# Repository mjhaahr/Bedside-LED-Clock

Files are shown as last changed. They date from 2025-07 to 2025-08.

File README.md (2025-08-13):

# RGB LED 7-Segment Bedside Clock with Ambient Light and Proximity Sensor

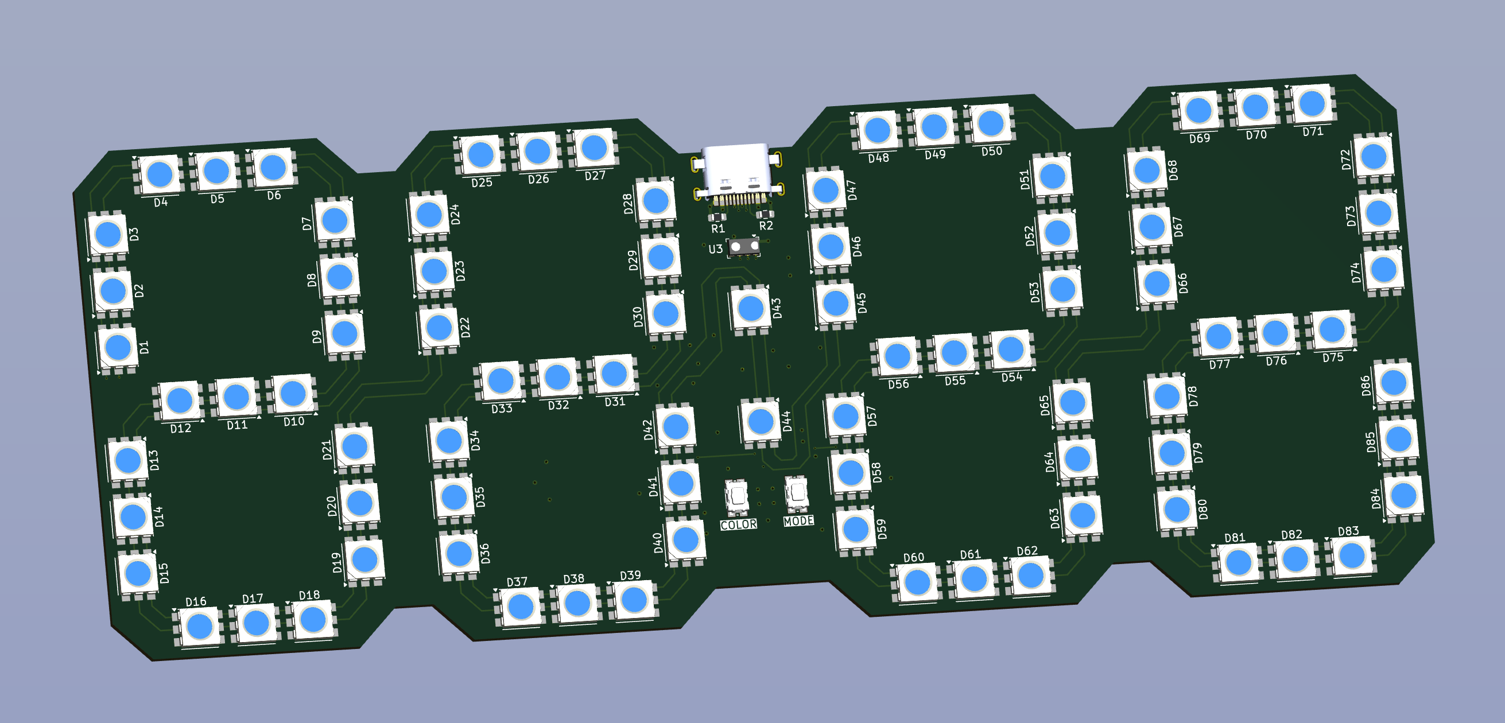
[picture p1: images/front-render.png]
Full Board Design Render - Front

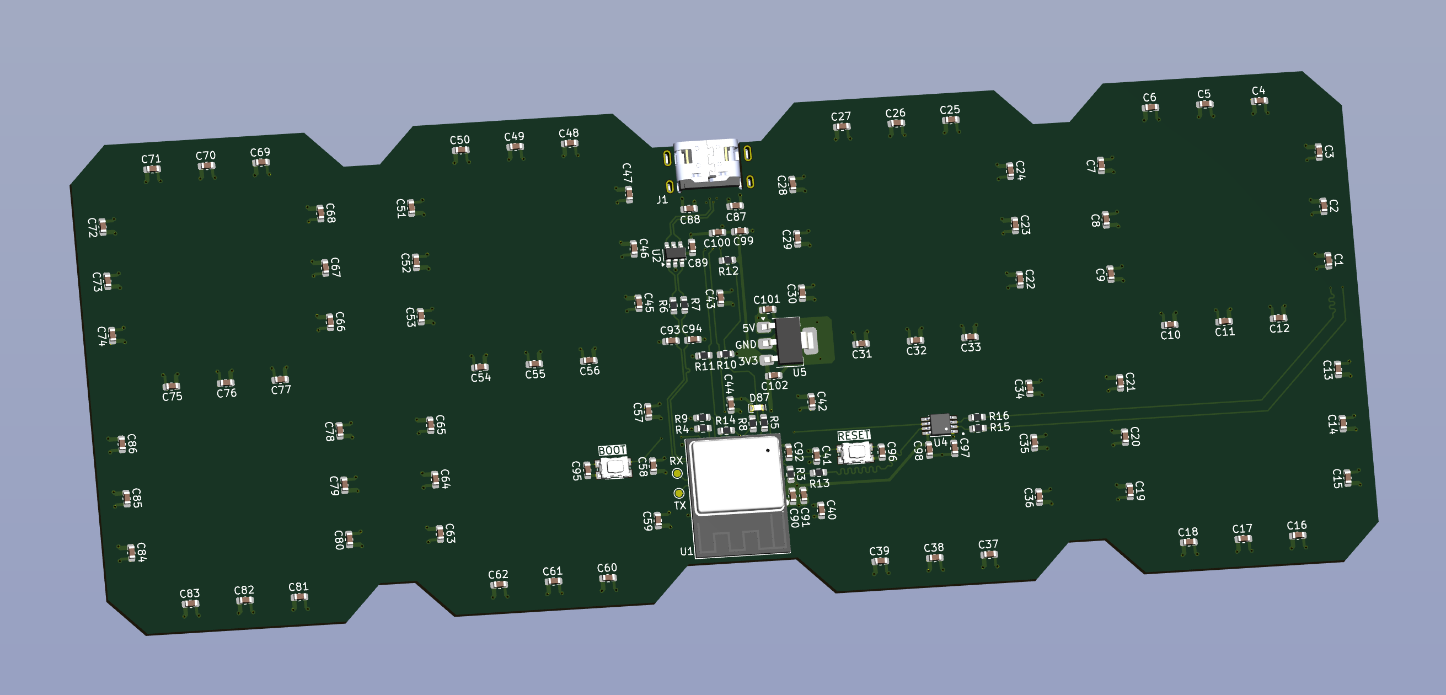
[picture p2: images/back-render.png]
Full Board Design Render - Back


## Features
- USB C Port for Power, Comms, and Programming
    - Connects to the ESP32-C3's onboard USB-CDC/JTAG device
- ESP32-C3 Module for control
    - Allows pattern changing over WiFi/Bluetooth, as well as the buttons on the device
- Integrated Ambient Light and Proximity Sensor
    - Allows the clock to be used at night and stay idle unless desired
- 86 Addressable RGB LEDs
    - APA102-style (DotStar) 2-Wire Control with Global Dimmer and Clock
    - HD107S-5050
    
## Table Of Contents
- [Features](#features)
- [Bill Of Materials](#bill-of-materials)
- [Part Selection](#part-selection)
- [Case Design](#case-design)
- [Code](#code)
- [Extra Notes](#extra-notes)

Main Schematic
Digit Schematic (Repeated 4x)

## Bill of Materials
<!--  
- NAME - FUNC
    - Component: REF
    - Quantity: 
    - [Datasheet]()
    - [DigiKey]()
-->
- Espressif ESP32-C3-MINI-1 - Microcontroller Module w/ WiFi and Bluetooth
    - Component: U1
    - Quantity: 1
    - [Datasheet](https://www.espressif.com/sites/default/files/documentation/esp32-c3-mini-1_datasheet_en.pdf)
    - [DigiKey](https://www.digikey.com/en/products/detail/espressif-systems/ESP32-C3-MINI-1-N4-A/15817506)
- STMicroelectronics USBLC6-2SC6 - USB Data and Power TVS Diode
    - Component: U2
    - Quantity: 1
    - [Datasheet](https://www.st.com/content/ccc/resource/technical/document/datasheet/06/1d/48/9c/6c/20/4a/b2/CD00050750.pdf/files/CD00050750.pdf/jcr:content/translations/en.CD000507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)
    - [DigiKey](https://www.digikey.com/en/products/detail/stmicroelectronics/USBLC6-2SC6/1040559)
- Vishay VCNL4040M3OE - Combination Ambient Light and Proximity Sensor
    - Component: U3
    - Quantity: 1
    - [Datasheet](https://www.vishay.com/docs/84274/vcnl4040.pdf)
    - [DigiKey](https://www.digikey.com/en/products/detail/vishay-semiconductor-opto-division/VCNL4040M3OE/5171283)
- TI SN74LVC2T45DCTR - Two Channel Fast Level Shifter (from 3V3 MCU to 5V LEDs)
    - Component: U4
    - Quantity: 1
    - [Datasheet](https://www.ti.com/lit/ds/symlink/sn74lvc2t45.pdf)
    - [DigiKey](https://www.digikey.com/en/products/detail/texas-instruments/SN74LVC2T45DCTR/639457)
- Microchip MCP1825ST-3302E/DB - 3V3 Low Noise LDO (500mA)
    - Component: U5
    - Quantity: 1
    - [Datasheet](https://ww1.microchip.com/downloads/en/DeviceDoc/22056b.pdf)
    - [DigiKey](https://www.digikey.com/en/products/detail/microchip-technology/MCP1825ST-3302E-DB/1635518)
- HD107S - APA102 Style Addressable RGB LED with Global Dimmer and Clock 
    - Component: D1 - D86
    - Quantity: 86
    - [Datasheet](https://cdn.hackaday.io/files/1677667177700544/HD107S%20%20Pixel%20RGB%205050%20LED%20chip%20%20Specificaion%20V1.0.1.pdf)
    - [LED Lighting Hut](https://www.ledlightinghut.com/hd107s-5050-rgb-led.html)
- Würth Elektronik 150060VS55040 - Green Indicator LED (LED_BUILTIN)
    - Component: D87
    - Quantity: 1
    - [Datasheet](https://www.we-online.com/components/products/datasheet/150060VS55040.pdf)
    - [DigiKey](https://www.digikey.com/en/products/detail/w%C3%BCrth-elektronik/150060VS55040/8557182)
- GCT USB4520-03-0-A - Midmount USB 2.0 Type C Port
    - Component: J1
    - Quantity: 1
    - [Datasheet](https://gct.co/files/specs/usb4520-spec.pdf)
    - [DigiKey](https://www.digikey.com/en/products/detail/gct/USB4520-03-0-A/15283199)
- E-Switch TL6330AF200Q - Tactile Normally Open Push Button 
    - Component: SW1 - SW4
    - Quantity: 4
    - [Datasheet](https://configured-product-images.s3.amazonaws.com/Datasheets/TL6330.pdf)
    - [DigiKey](https://www.digikey.com/en/products/detail/e-switch/TL6330AF200Q/8032037)
- 100nF - Yageo 0603 Ceramic Capacitor
    - Component: C1 - C86, C89, C91, C96, C98, C99
    - Quantity: 13
    - [DigiKey](https://www.digikey.com/en/products/detail/yageo/CC0603KRX7R7BB104/302822)
- 1µF - Yageo 0603 Ceramic Capacitor
    - Component: C87, C92, C102
    - Quantity: 3
    - [DigiKey](https://www.digikey.com/en/products/detail/yageo/CC0603KRX5R8BB105/2833610)
- 10µF - Yageo 0603 Ceramic Capacitor
    - Component: C88, C90, C97
    - Quantity: 3
    - [DigiKey](https://www.digikey.com/en/products/detail/yageo/CC0603MRX5R6BB106/5195224)
- 22pF - Yageo 0603 Ceramic Capacitor
    - Component: C93, C94
    - Quantity: 2
    - [DigiKey](https://www.digikey.com/en/products/detail/yageo/CC0603JRNPO8BN220/5883592)
- 2.2µF - Yageo 0603 Ceramic Capacitor
    - Component: C100
    - Quantity: 1
    - [DigiKey](https://www.digikey.com/en/products/detail/yageo/CC0603KRX5R7BB225/5195192)
- 4.7µF - Yageo 0603 Ceramic Capacitor
    - Component: C101
    - Quantity: 1
    - [DigiKey](https://www.digikey.com/en/products/detail/yageo/CC0603KRX5R7BB475/5195193)
- 5.1kΩ - Yageo 0603 SMD Resistor
    - Component: R1, R2
    - Quantity: 2
    - [DigiKey](https://www.digikey.com/en/products/detail/yageo/RC0603FR-075K1L/727268)
- 10kΩ - Yageo 0603 SMD Resistor
    - Component: R3, R4, R8, R9
    - Quantity: 4
    - [DigiKey](https://www.digikey.com/en/products/detail/yageo/RC0603FR-1010KL/12756395)
- 1.43kΩ - Yageo 0603 SMD Resistor
    - Component: R5
    - Quantity: 1
    - [DigiKey](https://www.digikey.com/en/products/detail/yageo/RC0603FR-071K43L/726862)
- 0Ω - Yageo 0603 SMD Resistor
    - Component: R6, R7
    - Quantity: 2
    - [DigiKey](https://www.digikey.com/en/products/detail/yageo/RC0603JR-070RL/726675)
- 3.3kΩ - Yageo 0603 SMD Resistor
    - Component: R10, R11
    - Quantity: 2
    - [DigiKey](https://www.digikey.com/en/products/detail/yageo/RC0603FR-073K3L/727126)
- 8.2kΩ - Yageo 0603 SMD Resistor
    - Component: R12
    - Quantity: 1
    - [DigiKey](https://www.digikey.com/en/products/detail/yageo/RC0603FR-078K2L/727390)
- 33Ω - Yageo 0603 SMD Resistor
    - Component: R13 - R16
    - Quantity: 4
    - [DigiKey](https://www.digikey.com/en/products/detail/yageo/RC0603FR-0733RL/727158)

## Case Design
<!--  TODO: Case design needs to be updated  -->
<!--  ![Case](images/case.png)  -->
- 3D Printed Chassis

## Code
<!-- Nothing Written Yet -->
- To view all the code, see it [here](code)

## Extra Notes

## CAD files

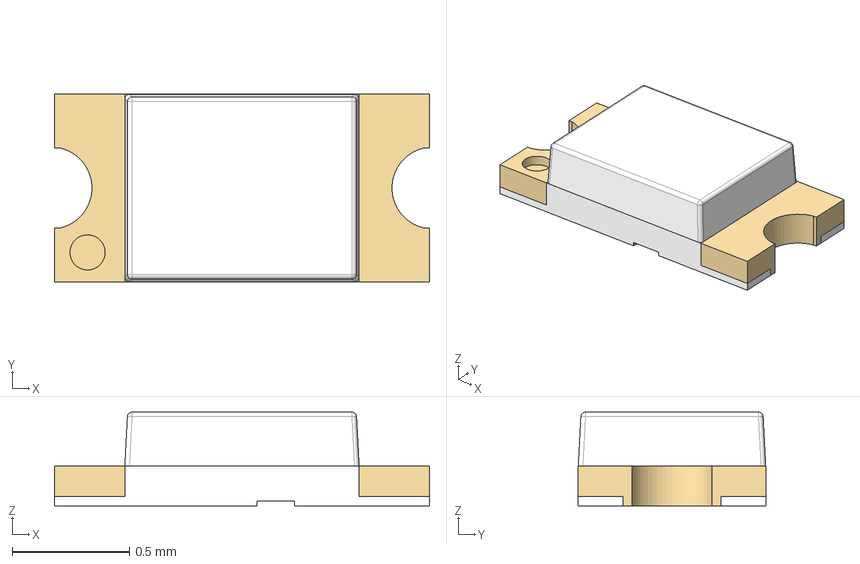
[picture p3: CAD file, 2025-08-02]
Bedside_Clock/parts/150060VS55040/WL-SMCD_0603.step
1.60 x 0.8 x 0.4 mm
housing
cover
base-oa0
base

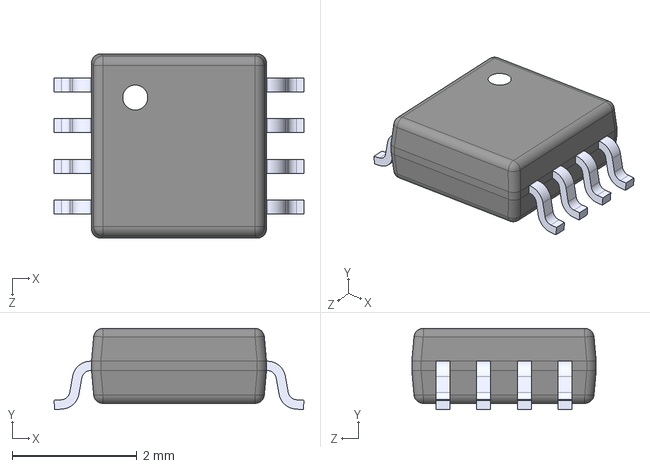
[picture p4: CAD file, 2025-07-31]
Bedside_Clock/parts/SN74LVC2T45DCTR/SN74LVC2T45DCTR.step
4.00 x 1.30 x 2.95 mm

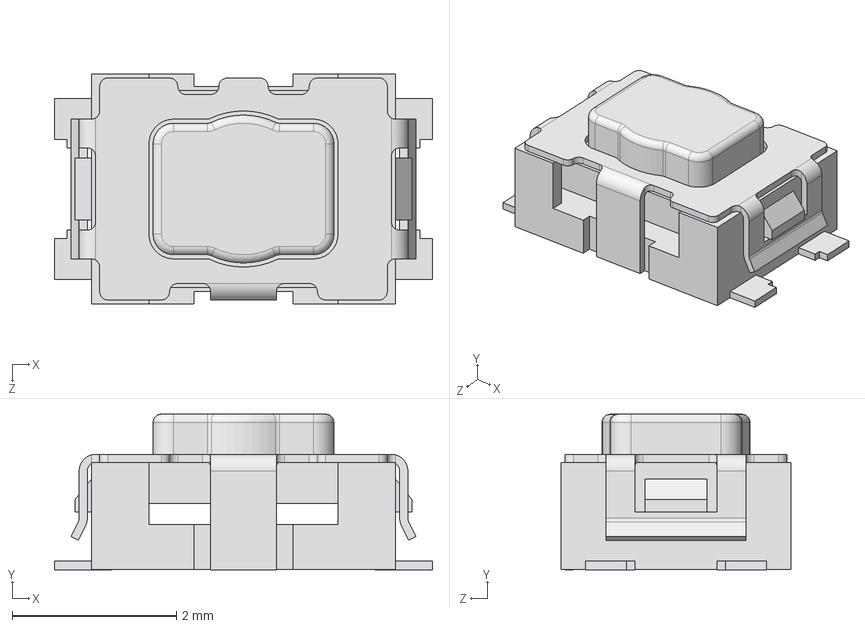
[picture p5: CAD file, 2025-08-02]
Bedside_Clock/parts/TL6330AF200Q/TL6330AF200Q.step
4.60 x 1.90 x 2.80 mm

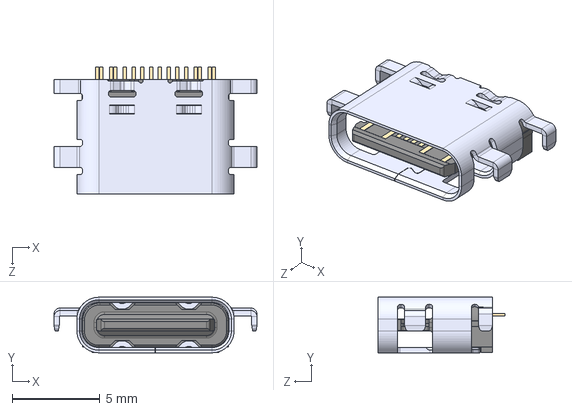
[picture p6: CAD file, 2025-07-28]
Bedside_Clock/parts/USB4520_03_0_A/USB4520-03-0-A_REVA.step
11.5 x 3.16 x 7.20 mm

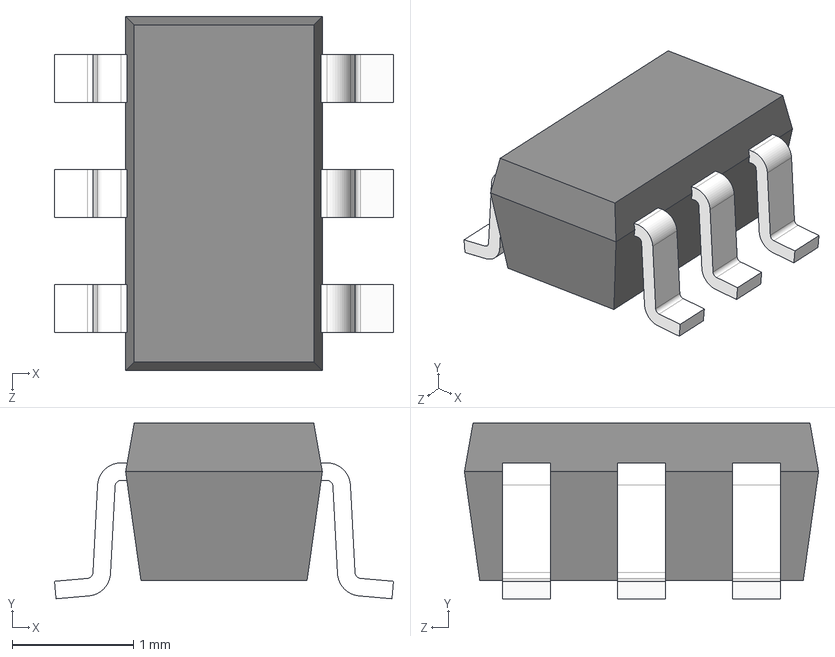
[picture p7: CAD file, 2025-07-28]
Bedside_Clock/parts/USBLC6_2SC6/USBLC6-2SC6.step
2.80 x 1.45 x 2.92 mm

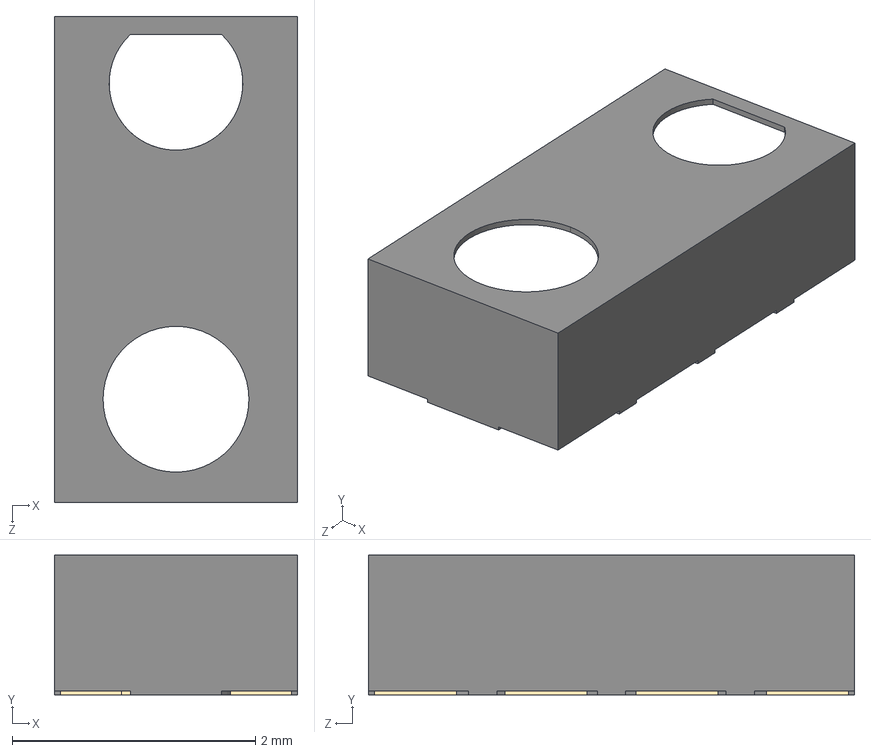
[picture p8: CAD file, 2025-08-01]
Bedside_Clock/parts/VCNL4040M3OE/VCNL4040M3OE.step
2.00 x 1.15 x 4.00 mm

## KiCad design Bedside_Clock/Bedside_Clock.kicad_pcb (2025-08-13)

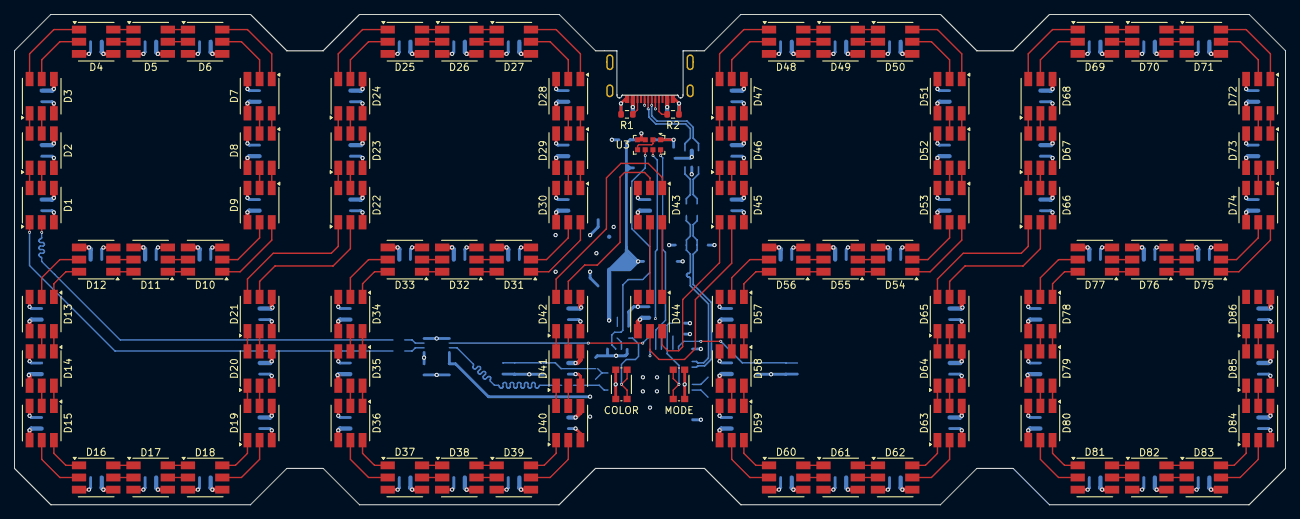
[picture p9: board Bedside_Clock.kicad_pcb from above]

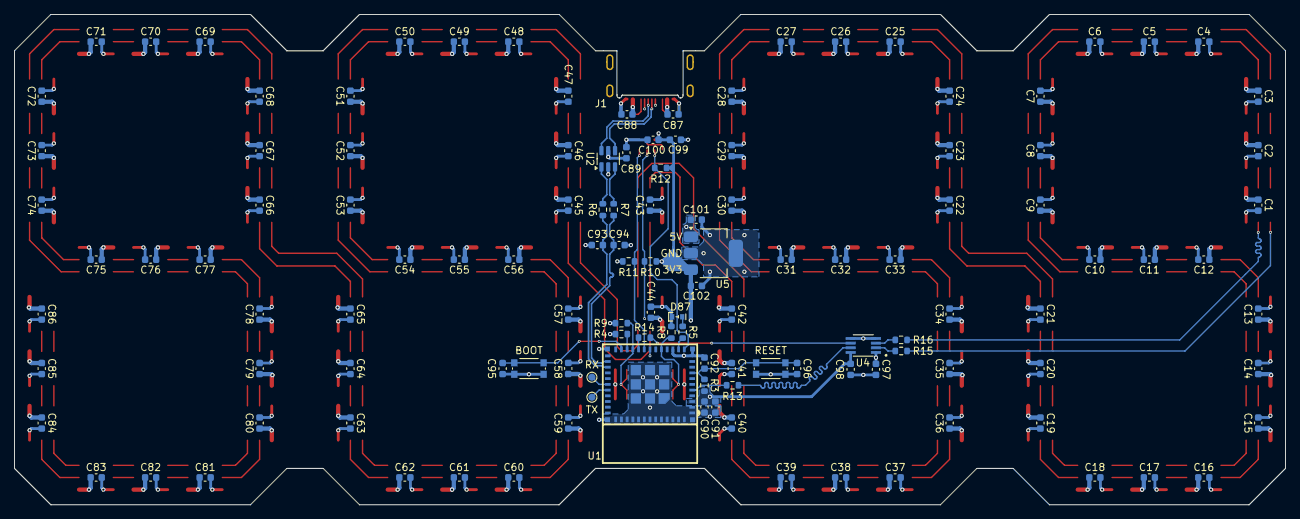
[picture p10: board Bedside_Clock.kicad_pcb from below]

Board: 4 copper layers, 177.8 x 68.6 mm, 217 parts (125 on the bottom side), 202 nets.

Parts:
C1, C2, C3, C4, C5, C6, C7, C8, C9, C10, C11, C12, C13, C14, C15, C16, C17, C18, C19, C20, C21, C22, C23, C24, C25, C26, C27, C28, C29, C30, C31, C32, C33, C34, C35, C36, C37, C38, C39, C40, C41, C42, C43, C44, C45, C46, C47, C48, C49, C50, C51, C52, C53, C54, C55, C56, C57, C58, C59, C60, C61, C62, C63, C64, C65, C66, C67, C68, C69, C70, C71, C72, C73, C74, C75, C76, C77, C78, C79, C80, C81, C82, C83, C84, C85, C86, C89, C91, C95, C96, C98, C99: 100nF; C_0603_1608Metric
C87, C92, C102: 1uF; C_0603_1608Metric
C88, C90, C97: 10uF; C_0603_1608Metric
C93, C94: 22pF; C_0603_1608Metric
C100: 2.2uF; C_0603_1608Metric
C101: 4.7uF; C_0603_1608Metric
D1, D2, D3, D4, D5, D6, D7, D8, D9, D10, D11, D12, D13, D14, D15, D16, D17, D18, D19, D20, D21, D22, D23, D24, D25, D26, D27, D28, D29, D30, D31, D32, D33, D34, D35, D36, D37, D38, D39, D40, D41, D42, D43, D44, D45, D46, D47, D48, D49, D50, D51, D52, D53, D54, D55, D56, D57, D58, D59, D60, D61, D62, D63, D64, D65, D66, D67, D68, D69, D70, D71, D72, D73, D74, D75, D76, D77, D78, D79, D80, D81, D82, D83, D84, D85, D86: HD107S; LED_RGB_5050-6
D87: WL-SMCD_0603
J1: USBC_USB2.0; GCT_USB4520-03-0-A_REVA
R1, R2: 5k1; R_0603_1608Metric
R3, R4, R8, R9: 10k; R_0603_1608Metric
R5: 1k43; R_0603_1608Metric
R6, R7: 0; R_0603_1608Metric
R10, R11: 3k3; R_0603_1608Metric
R12: 8k2; R_0603_1608Metric
R13, R14, R15, R16: 33; R_0603_1608Metric
SW1: COLOR; SW_TL6330AF200Q
SW2: MODE; SW_TL6330AF200Q
SW3: BOOT; SW_TL6330AF200Q
SW4: RESET; SW_TL6330AF200Q
TP1: TX; TestPoint_Pad_D1.0mm
TP2: RX; TestPoint_Pad_D1.0mm
U1: ESP32-C3-MINI-1; WIFIM-SMD_ESP32-C3-MINI-1
U2: USBLC6-2SC6; SOT-23-6
U3: VCNL4040M3OE; VISHAY_VCNL4040_4X2X1.1
U4: SN74LVC2T45DCTR; SOP65P400X130-8N
U5: MCP1825S; SOT-223-3_TabPin2

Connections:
+3V3: C90.1, C91.1, C98.1, C99.1, C100.1, C102.1, R3.1, R4.2, R10.2, R11.2, R12.2, SW1.1, SW1.2, SW2.1, SW2.2, U1.3 (3V3), U3.3, U3.4, U4.8 (VCCB), U5.3 (VO)
+5V: C1.1, C2.1, C3.1, C4.1, C5.1, C6.1, C7.1, C8.1, C9.1, C10.1, C11.1, C12.1, C13.1, C14.1, C15.1, C16.1, C17.1, C18.1, C19.1, C20.1, C21.1, C22.1, C23.1, C24.1, C25.1, C26.1, C27.1, C28.1, C29.1, C30.1, C31.1, C32.1, C33.1, C34.1, C35.1, C36.1, C37.1, C38.1, C39.1, C40.1, C41.1, C42.1, C43.1, C44.1, C45.1, C46.1, C47.1, C48.1, C49.1, C50.1, C51.1, C52.1, C53.1, C54.1, C55.1, C56.1, C57.1, C58.1, C59.1, C60.1, C61.1, C62.1, C63.1, C64.1, C65.1, C66.1, C67.1, C68.1, C69.1, C70.1, C71.1, C72.1, C73.1, C74.1, C75.1, C76.1, C77.1, C78.1, C79.1, C80.1, C81.1, C82.1, C83.1, C84.1, C85.1, C86.1, C87.1, C88.1, C89.1, C97.1, C101.1, D1.4 (VCC), D2.4 (VCC), D3.4 (VCC), D4.4 (VCC), D5.4 (VCC), D6.4 (VCC), D7.4 (VCC), D8.4 (VCC), D9.4 (VCC), D10.4 (VCC), D11.4 (VCC), D12.4 (VCC), D13.4 (VCC), D14.4 (VCC), D15.4 (VCC), D16.4 (VCC), D17.4 (VCC), D18.4 (VCC), D19.4 (VCC), D20.4 (VCC), D21.4 (VCC), D22.4 (VCC), D23.4 (VCC), D24.4 (VCC), D25.4 (VCC), D26.4 (VCC), D27.4 (VCC), D28.4 (VCC), D29.4 (VCC), D30.4 (VCC), D31.4 (VCC), D32.4 (VCC), D33.4 (VCC), D34.4 (VCC), D35.4 (VCC), D36.4 (VCC), D37.4 (VCC), D38.4 (VCC), D39.4 (VCC), D40.4 (VCC), D41.4 (VCC), D42.4 (VCC), D43.4 (VCC), D44.4 (VCC), D45.4 (VCC), D46.4 (VCC), D47.4 (VCC), D48.4 (VCC), D49.4 (VCC), D50.4 (VCC), D51.4 (VCC), D52.4 (VCC), D53.4 (VCC), D54.4 (VCC), D55.4 (VCC), D56.4 (VCC), D57.4 (VCC), D58.4 (VCC), D59.4 (VCC), D60.4 (VCC), D61.4 (VCC), D62.4 (VCC), D63.4 (VCC), D64.4 (VCC), D65.4 (VCC), D66.4 (VCC), D67.4 (VCC), D68.4 (VCC), D69.4 (VCC), D70.4 (VCC), D71.4 (VCC), D72.4 (VCC), D73.4 (VCC), D74.4 (VCC), D75.4 (VCC), D76.4 (VCC), D77.4 (VCC), D78.4 (VCC), D79.4 (VCC), D80.4 (VCC), D81.4 (VCC), D82.4 (VCC), D83.4 (VCC), D84.4 (VCC), D85.4 (VCC), D86.4 (VCC), J1.A4_B9 (VBUS), J1.B4_A9 (VBUS), U2.5 (VBUS), U4.1 (VCCA), U5.1 (VI)
/BOOT: C95.1, SW3.1, SW3.2, U1.23 (GPIO9)
/CC1: J1.A5 (CC1), R2.2
/CC2: J1.B5 (CC2), R1.2
/CHIP_EN: C92.1, C96.1, R3.2, SW4.1, SW4.2, U1.8 (EN/CHIP_PU)
/CO: R14.2, U4.6 (B2)
/CO': R14.1, U1.20 (GPIO6)
/CO'': R16.1, U4.3 (A2)
/COLOR: R8.1, SW1.3, SW1.4, U1.16 (GPIO10)
/DO: R13.2, U4.7 (B1)
/DO': R13.1, U1.5 (GPIO2/ADC1_CH2)
/DO'': R15.1, U4.2 (A1)
/Digit0/CI: D1.2 (CI), R16.2
/Digit0/CO: D21.5 (CO), D22.2 (CI)
/Digit0/DI: D1.1 (DI), R15.2
/Digit0/DO: D21.6 (DO), D22.1 (DI)
/Digit1/CO: D42.5 (CO), D43.2 (CI)
/Digit1/DO: D42.6 (DO), D43.1 (DI)
/Digit2/CI: D44.5 (CO), D45.2 (CI)
/Digit2/CO: D65.5 (CO), D66.2 (CI)
/Digit2/DI: D44.6 (DO), D45.1 (DI)
/Digit2/DO: D65.6 (DO), D66.1 (DI)
/LED_BUILTIN: R5.2, U1.13 (GPIO1/ADC1_CH1/XTAL_32K_N)
/MODE: R9.1, SW2.3, SW2.4, U1.21 (GPIO7)
/PROX_INT: R12.1, U1.12 (GPIO0/ADC1_CH0/XTAL_32K_P), U3.6
/SCL: R11.1, U1.19 (GPIO5/ADC2_CH0), U3.8
/SDA: R10.1, U1.18 (GPIO4/ADC1_CH4), U3.7
/UD''+: J1.A6 (D+), J1.B6 (D+), U2.6 (I/O1)
/UD''-: J1.A7 (D-), J1.B7 (D-), U2.4 (I/O2)
/UD'+: C93.1, R6.1, U1.27 (GPIO19/USB_D+)
/UD'-: C94.1, R7.1, U1.26 (GPIO18/USB_D-)
/UD+: R6.2, U2.1 (I/O1)
/UD-: R7.2, U2.3 (I/O2)
GND: C1.2, C2.2, C3.2, C4.2, C5.2, C6.2, C7.2, C8.2, C9.2, C10.2, C11.2, C12.2, C13.2, C14.2, C15.2, C16.2, C17.2, C18.2, C19.2, C20.2, C21.2, C22.2, C23.2, C24.2, C25.2, C26.2, C27.2, C28.2, C29.2, C30.2, C31.2, C32.2, C33.2, C34.2, C35.2, C36.2, C37.2, C38.2, C39.2, C40.2, C41.2, C42.2, C43.2, C44.2, C45.2, C46.2, C47.2, C48.2, C49.2, C50.2, C51.2, C52.2, C53.2, C54.2, C55.2, C56.2, C57.2, C58.2, C59.2, C60.2, C61.2, C62.2, C63.2, C64.2, C65.2, C66.2, C67.2, C68.2, C69.2, C70.2, C71.2, C72.2, C73.2, C74.2, C75.2, C76.2, C77.2, C78.2, C79.2, C80.2, C81.2, C82.2, C83.2, C84.2, C85.2, C86.2, C87.2, C88.2, C89.2, C90.2, C91.2, C92.2, C93.2, C94.2, C95.2, C96.2, C97.2, C98.2, C99.2, C100.2, C101.2, C102.2, D1.3 (GND), D2.3 (GND), D3.3 (GND), D4.3 (GND), D5.3 (GND), D6.3 (GND), D7.3 (GND), D8.3 (GND), D9.3 (GND), D10.3 (GND), D11.3 (GND), D12.3 (GND), D13.3 (GND), D14.3 (GND), D15.3 (GND), D16.3 (GND), D17.3 (GND), D18.3 (GND), D19.3 (GND), D20.3 (GND), D21.3 (GND), D22.3 (GND), D23.3 (GND), D24.3 (GND), D25.3 (GND), D26.3 (GND), D27.3 (GND), D28.3 (GND), D29.3 (GND), D30.3 (GND), D31.3 (GND), D32.3 (GND), D33.3 (GND), D34.3 (GND), D35.3 (GND), D36.3 (GND), D37.3 (GND), D38.3 (GND), D39.3 (GND), D40.3 (GND), D41.3 (GND), D42.3 (GND), D43.3 (GND), D44.3 (GND), D45.3 (GND), D46.3 (GND), D47.3 (GND), D48.3 (GND), D49.3 (GND), D50.3 (GND), D51.3 (GND), D52.3 (GND), D53.3 (GND), D54.3 (GND), D55.3 (GND), D56.3 (GND), D57.3 (GND), D58.3 (GND), D59.3 (GND), D60.3 (GND), D61.3 (GND), D62.3 (GND), D63.3 (GND), D64.3 (GND), D65.3 (GND), D66.3 (GND), D67.3 (GND), D68.3 (GND), D69.3 (GND), D70.3 (GND), D71.3 (GND), D72.3 (GND), D73.3 (GND), D74.3 (GND), D75.3 (GND), D76.3 (GND), D77.3 (GND), D78.3 (GND), D79.3 (GND), D80.3 (GND), D81.3 (GND), D82.3 (GND), D83.3 (GND), D84.3 (GND), D85.3 (GND), D86.3 (GND), D87.1, J1.A1_B12 (GND), J1.B1_A12 (GND), J1.S1 (SHIELD), J1.S2 (SHIELD), J1.S3 (SHIELD), J1.S4 (SHIELD), R1.1, R2.1, R8.2, R9.2, SW3.3, SW3.4, SW4.3, SW4.4, U1.1 (GND), U1.2 (GND), U1.11 (GND), U1.14 (GND), U1.36 (GND), U1.37 (GND), U1.38 (GND), U1.39 (GND), U1.40 (GND), U1.41 (GND), U1.42 (GND), U1.43 (GND), U1.44 (GND), U1.45 (GND), U1.46 (GND), U1.47 (GND), U1.48 (GND), U1.49 (GND), U1.50 (GND), U1.51 (GND), U1.52 (GND), U1.53 (GND), U2.2 (GND), U3.1, U4.4 (GND), U4.5 (DIR), U5.2 (GND)
unnamed: D1.5 (CO), D2.2 (CI)
unnamed: D1.6 (DO), D2.1 (DI)
unnamed: D2.5 (CO), D3.2 (CI)
unnamed: D2.6 (DO), D3.1 (DI)
unnamed: D3.5 (CO), D4.2 (CI)
unnamed: D3.6 (DO), D4.1 (DI)
unnamed: D4.5 (CO), D5.2 (CI)
unnamed: D4.6 (DO), D5.1 (DI)
unnamed: D5.5 (CO), D6.2 (CI)
unnamed: D5.6 (DO), D6.1 (DI)
unnamed: D6.5 (CO), D7.2 (CI)
unnamed: D6.6 (DO), D7.1 (DI)
unnamed: D7.5 (CO), D8.2 (CI)
unnamed: D7.6 (DO), D8.1 (DI)
unnamed: D8.5 (CO), D9.2 (CI)
unnamed: D8.6 (DO), D9.1 (DI)
unnamed: D9.5 (CO), D10.2 (CI)
unnamed: D10.5 (CO), D11.2 (CI)
unnamed: D9.6 (DO), D10.1 (DI)
unnamed: D10.6 (DO), D11.1 (DI)
unnamed: D11.5 (CO), D12.2 (CI)
unnamed: D11.6 (DO), D12.1 (DI)
unnamed: D12.5 (CO), D13.2 (CI)
unnamed: D12.6 (DO), D13.1 (DI)
unnamed: D13.5 (CO), D14.2 (CI)
unnamed: D13.6 (DO), D14.1 (DI)
unnamed: D14.5 (CO), D15.2 (CI)
unnamed: D14.6 (DO), D15.1 (DI)
unnamed: D15.5 (CO), D16.2 (CI)
unnamed: D15.6 (DO), D16.1 (DI)
unnamed: D16.5 (CO), D17.2 (CI)
unnamed: D16.6 (DO), D17.1 (DI)
unnamed: D17.5 (CO), D18.2 (CI)
unnamed: D17.6 (DO), D18.1 (DI)
unnamed: D18.5 (CO), D19.2 (CI)
unnamed: D18.6 (DO), D19.1 (DI)
unnamed: D19.5 (CO), D20.2 (CI)
unnamed: D19.6 (DO), D20.1 (DI)
unnamed: D20.5 (CO), D21.2 (CI)
unnamed: D20.6 (DO), D21.1 (DI)
unnamed: D22.5 (CO), D23.2 (CI)
unnamed: D22.6 (DO), D23.1 (DI)
unnamed: D23.5 (CO), D24.2 (CI)
unnamed: D23.6 (DO), D24.1 (DI)
unnamed: D24.5 (CO), D25.2 (CI)
unnamed: D24.6 (DO), D25.1 (DI)
unnamed: D25.5 (CO), D26.2 (CI)
unnamed: D25.6 (DO), D26.1 (DI)
unnamed: D26.5 (CO), D27.2 (CI)
unnamed: D26.6 (DO), D27.1 (DI)
unnamed: D27.5 (CO), D28.2 (CI)
unnamed: D27.6 (DO), D28.1 (DI)
unnamed: D28.5 (CO), D29.2 (CI)
unnamed: D28.6 (DO), D29.1 (DI)
unnamed: D29.5 (CO), D30.2 (CI)
unnamed: D29.6 (DO), D30.1 (DI)
unnamed: D30.5 (CO), D31.2 (CI)
unnamed: D30.6 (DO), D31.1 (DI)
unnamed: D31.5 (CO), D32.2 (CI)
unnamed: D31.6 (DO), D32.1 (DI)
unnamed: D32.5 (CO), D33.2 (CI)
unnamed: D32.6 (DO), D33.1 (DI)
unnamed: D33.5 (CO), D34.2 (CI)
unnamed: D33.6 (DO), D34.1 (DI)
unnamed: D34.5 (CO), D35.2 (CI)
unnamed: D34.6 (DO), D35.1 (DI)
unnamed: D35.5 (CO), D36.2 (CI)
unnamed: D35.6 (DO), D36.1 (DI)
unnamed: D36.5 (CO), D37.2 (CI)
unnamed: D36.6 (DO), D37.1 (DI)
unnamed: D37.5 (CO), D38.2 (CI)
unnamed: D37.6 (DO), D38.1 (DI)
unnamed: D38.5 (CO), D39.2 (CI)
unnamed: D38.6 (DO), D39.1 (DI)
unnamed: D39.5 (CO), D40.2 (CI)
unnamed: D39.6 (DO), D40.1 (DI)
unnamed: D40.5 (CO), D41.2 (CI)
unnamed: D40.6 (DO), D41.1 (DI)
unnamed: D41.5 (CO), D42.2 (CI)
unnamed: D41.6 (DO), D42.1 (DI)
unnamed: D43.5 (CO), D44.2 (CI)
unnamed: D43.6 (DO), D44.1 (DI)
unnamed: D45.5 (CO), D46.2 (CI)
unnamed: D45.6 (DO), D46.1 (DI)
unnamed: D46.5 (CO), D47.2 (CI)
unnamed: D46.6 (DO), D47.1 (DI)
unnamed: D47.5 (CO), D48.2 (CI)
unnamed: D47.6 (DO), D48.1 (DI)
unnamed: D48.5 (CO), D49.2 (CI)
unnamed: D48.6 (DO), D49.1 (DI)
unnamed: D49.5 (CO), D50.2 (CI)
unnamed: D49.6 (DO), D50.1 (DI)
unnamed: D50.5 (CO), D51.2 (CI)
unnamed: D50.6 (DO), D51.1 (DI)
unnamed: D51.5 (CO), D52.2 (CI)
unnamed: D51.6 (DO), D52.1 (DI)
unnamed: D52.5 (CO), D53.2 (CI)
unnamed: D52.6 (DO), D53.1 (DI)
unnamed: D53.5 (CO), D54.2 (CI)
unnamed: D53.6 (DO), D54.1 (DI)
unnamed: D54.5 (CO), D55.2 (CI)
unnamed: D54.6 (DO), D55.1 (DI)
unnamed: D55.5 (CO), D56.2 (CI)
unnamed: D55.6 (DO), D56.1 (DI)
unnamed: D56.5 (CO), D57.2 (CI)
unnamed: D56.6 (DO), D57.1 (DI)
unnamed: D57.5 (CO), D58.2 (CI)
unnamed: D57.6 (DO), D58.1 (DI)
unnamed: D58.5 (CO), D59.2 (CI)
unnamed: D58.6 (DO), D59.1 (DI)
unnamed: D59.5 (CO), D60.2 (CI)
unnamed: D59.6 (DO), D60.1 (DI)
unnamed: D60.5 (CO), D61.2 (CI)
unnamed: D60.6 (DO), D61.1 (DI)
unnamed: D61.5 (CO), D62.2 (CI)
unnamed: D61.6 (DO), D62.1 (DI)
unnamed: D62.5 (CO), D63.2 (CI)
unnamed: D62.6 (DO), D63.1 (DI)
unnamed: D63.5 (CO), D64.2 (CI)
unnamed: D63.6 (DO), D64.1 (DI)
unnamed: D64.5 (CO), D65.2 (CI)
unnamed: D64.6 (DO), D65.1 (DI)
unnamed: D66.5 (CO), D67.2 (CI)
unnamed: D66.6 (DO), D67.1 (DI)
unnamed: D67.5 (CO), D68.2 (CI)
unnamed: D67.6 (DO), D68.1 (DI)
unnamed: D68.5 (CO), D69.2 (CI)
unnamed: D68.6 (DO), D69.1 (DI)
unnamed: D69.5 (CO), D70.2 (CI)
unnamed: D69.6 (DO), D70.1 (DI)
unnamed: D70.5 (CO), D71.2 (CI)
unnamed: D70.6 (DO), D71.1 (DI)
unnamed: D71.5 (CO), D72.2 (CI)
unnamed: D71.6 (DO), D72.1 (DI)
unnamed: D72.5 (CO), D73.2 (CI)
unnamed: D72.6 (DO), D73.1 (DI)
unnamed: D73.5 (CO), D74.2 (CI)
unnamed: D73.6 (DO), D74.1 (DI)
unnamed: D74.5 (CO), D75.2 (CI)
unnamed: D74.6 (DO), D75.1 (DI)
unnamed: D75.5 (CO), D76.2 (CI)
unnamed: D75.6 (DO), D76.1 (DI)
unnamed: D76.5 (CO), D77.2 (CI)
unnamed: D76.6 (DO), D77.1 (DI)
unnamed: D77.5 (CO), D78.2 (CI)
unnamed: D77.6 (DO), D78.1 (DI)
unnamed: D78.5 (CO), D79.2 (CI)
unnamed: D78.6 (DO), D79.1 (DI)
unnamed: D79.5 (CO), D80.2 (CI)
unnamed: D79.6 (DO), D80.1 (DI)
unnamed: D80.5 (CO), D81.2 (CI)
unnamed: D80.6 (DO), D81.1 (DI)
unnamed: D81.5 (CO), D82.2 (CI)
unnamed: D81.6 (DO), D82.1 (DI)
unnamed: D82.5 (CO), D83.2 (CI)
unnamed: D82.6 (DO), D83.1 (DI)
unnamed: D83.5 (CO), D84.2 (CI)
unnamed: D83.6 (DO), D84.1 (DI)
unnamed: D84.5 (CO), D85.2 (CI)
unnamed: D84.6 (DO), D85.1 (DI)
unnamed: D85.5 (CO), D86.2 (CI)
unnamed: D85.6 (DO), D86.1 (DI)
unnamed: D87.2, R5.1
unnamed: R4.1, U1.22 (GPIO8)
unnamed: TP2.1, U1.30 (GPIO20/U0RXD)
unnamed: TP1.1, U1.31 (GPIO21/U0TXD)
unnamed: U3.2, U3.5

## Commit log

2025-07-26 [HW] Start schematic work, adddd LEDs (yay for heirarchcial sheets) Lots of TODOs
    [Bedside_Clock.kicad_pcb, Bedside_Clock.kicad_sch, digit.kicad_sch]
2025-07-26 [HW] Switch to HD107s (maybe switch to 108s)
    [Bedside_Clock.kicad_sch, digit.kicad_sch]
2025-07-27 [HW] Layout LEDs and first pass add of ESP32 Also add decoupling caps for all LEDs
    [Bedside_Clock.kicad_pcb, Bedside_Clock.kicad_sch, digit.kicad_sch]
2025-07-27 [HW] Swap component names from SK9822 to HD107S
    [Bedside_Clock.kicad_pcb, Bedside_Clock.kicad_sch, digit.kicad_sch]
2025-07-27 [HW] Routing progress Need to close on some parts
    [Bedside_Clock.kicad_pcb, Bedside_Clock.kicad_sch, digit.kicad_sch]
2025-07-28 [HW] Switch to 4 layers
    [Bedside_Clock.kicad_pcb]
2025-07-28 [HW] Switch to 4 layers and m mid mount USB-C
    [Bedside_Clock.kicad_pcb, Bedside_Clock.kicad_sch, USB4520-03-0-A_REVA.step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]
2025-07-28 [HW] Clean up and layout improvements
    [Bedside_Clock.kicad_pcb, Bedside_Clock.kicad_sch]
2025-07-31 [HW] Add Ambient Light Sensor and Level Shifter
    [Bedside_Clock.kicad_pcb, Bedside_Clock.kicad_sch, SN74LVC2T45DCTR.step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]
2025-08-01 [HW] Switch Ambient Light sensor to have proximity
    [Bedside_Clock.kicad_pcb, Bedside_Clock.kicad_sch, VCNL4040M3OE.step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]
2025-08-02 [HW] Find all parts and finish layout
    [Bedside_Clock.kicad_pcb, Bedside_Clock.kicad_sch, TL6330AF200Q.step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]
2025-08-03 [Docs] Add Schematics and Renders Add Diodes, Switches, and Conns to BOM Need Resistors and Capacitors now
    [Bedside_Clock.kicad_pcb, Bedside_Clock.kicad_sch]
2025-08-03 [Docs] Finish BOM
    [Bedside_Clock.kicad_sch]
2025-08-13 [HW] Add Series Resistors for SPI/LED Data (can be replaced with 0Ω if necessary) SPI Routing clean up to allow series resistors Also cleaned up some usage notes
    [Bedside_Clock.kicad_pcb, Bedside_Clock.kicad_sch]
